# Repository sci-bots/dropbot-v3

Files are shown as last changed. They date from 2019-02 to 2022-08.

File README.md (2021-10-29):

# DropBot v3

[This wiki](https://github.com/sci-bots/dropbot-v3/wiki/) contains documentation for the DropBot Digital Microfluidics (DMF) automation system. This is the latest generation DropBot instrument (v3) which makes many improvements over the previous hardware. These systems are available for purchase from [Sci-Bots](https://sci-bots.com/dropbot).

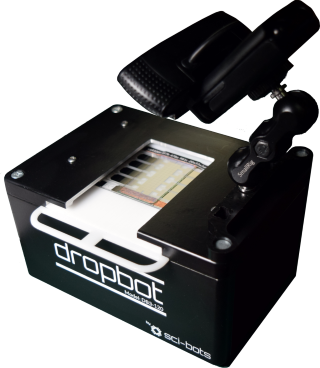
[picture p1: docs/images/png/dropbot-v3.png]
DropBot v3 (https://sci-bots.com/dropbot)


The original DropBot system was developed in the [Wheeler Lab at the University of Toronto](http://microfluidics.utoronto.ca/dropbot) and is described in detail in [Fobel et al., Appl. Phys. Lett. 102, 193513 (2013); doi: 10.1063/1.4807118](http://dx.doi.org/10.1063/1.4807118).

All hardware and software are open-source, subject to the [BSD-3-Clause license](https://github.com/sci-bots/microdrop/blob/master/LICENSE.md) (software code) or [Creative Commons Attribution-ShareAlike license](http://creativecommons.org/licenses/by-sa/3.0) (hardware designs).

If you have questions or feedback or would like to collaborate on the development of this project, please join our [community forum](https://forum.sci-bots.com). New users should checkout the [User Guide](https://github.com/sci-bots/dropbot-v3/wiki/UserGuide). If you're having problems with your DropBot, checkout the [Troubleshooting Guide](https://github.com/sci-bots/dropbot-v3/wiki/Troubleshooting).

Sci-Bots logo (https://sci-bots.com/dropbot)

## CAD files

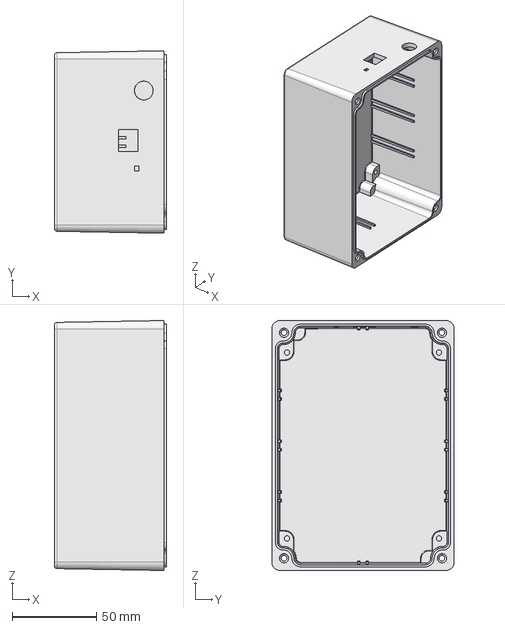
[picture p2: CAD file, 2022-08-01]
docs/step files/enclosure/Case.step
66.5 x 108.0 x 148.0 mm

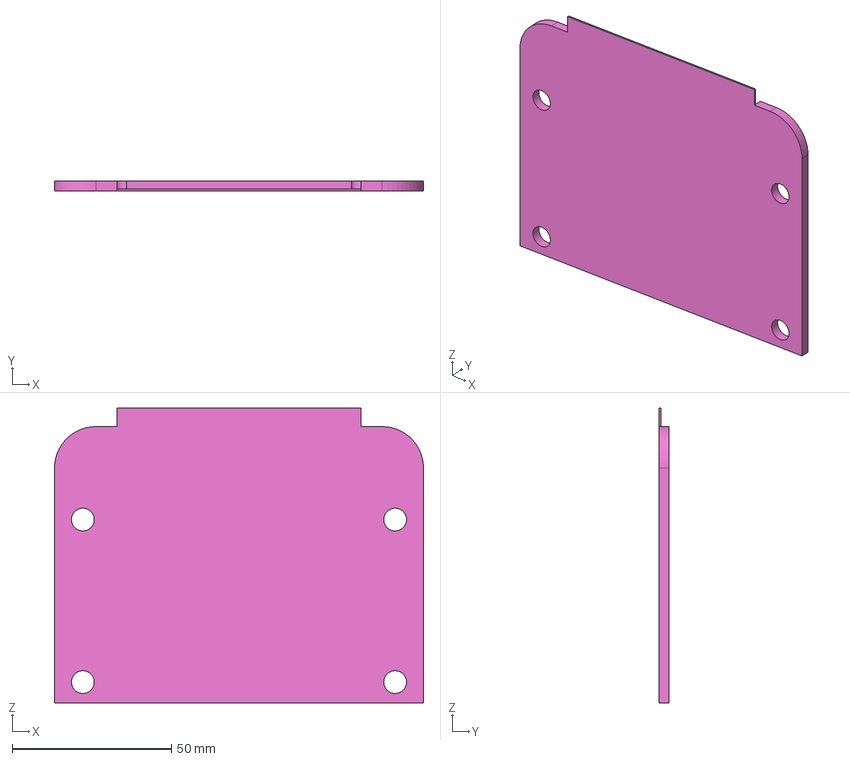
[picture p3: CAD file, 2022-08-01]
docs/step files/inner parts/Chip Guide - W115.809 x D92.555 x H3.175 mm v8 v7.step
115.8 x 3.18 x 92.6 mm

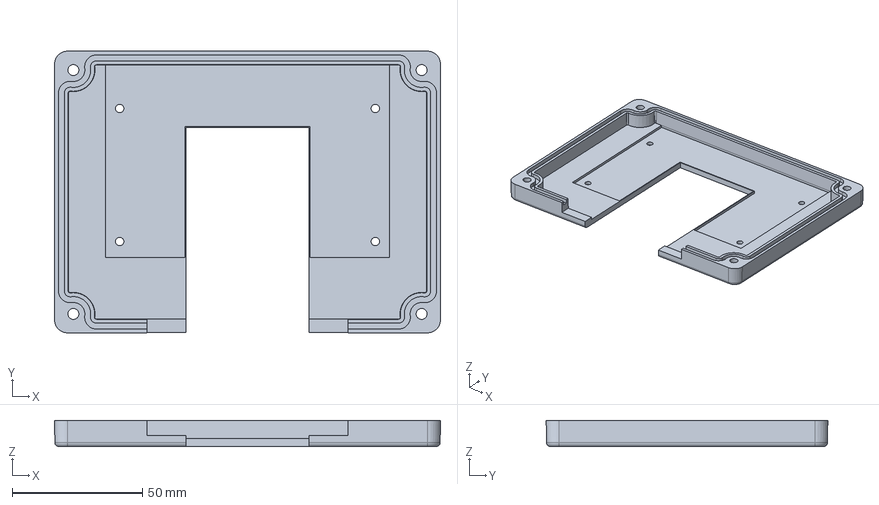
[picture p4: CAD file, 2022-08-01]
docs/step files/enclosure/Cover.step
148.0 x 108.0 x 10.0 mm

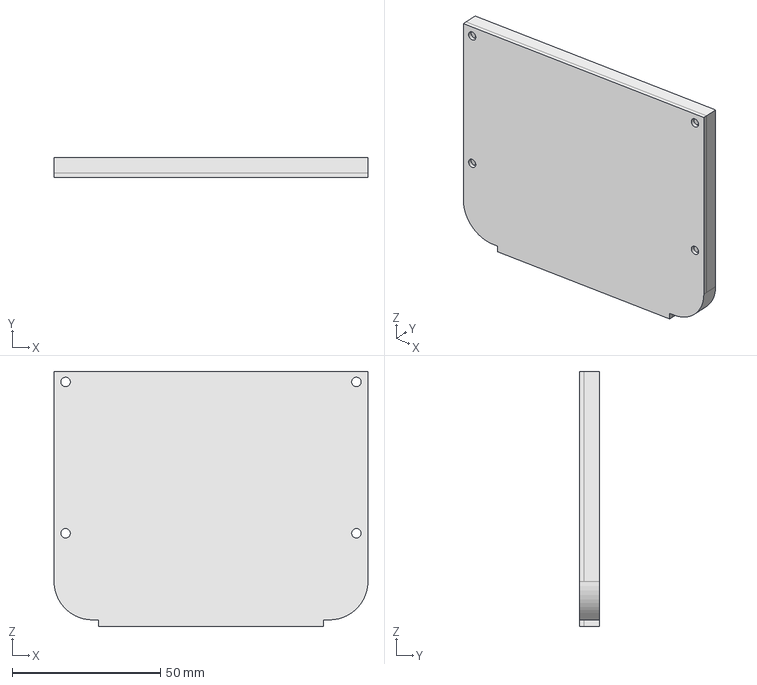
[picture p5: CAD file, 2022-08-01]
docs/step files/inner parts/base plate v6 v7.step
105.8 x 6.67 x 86.0 mm

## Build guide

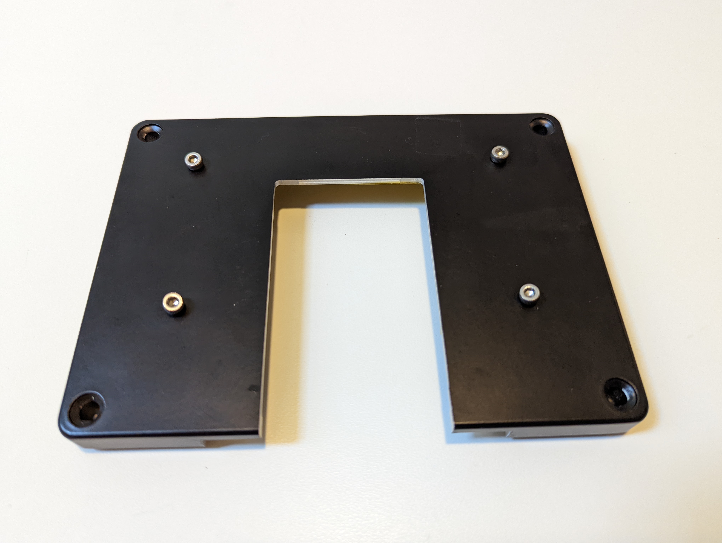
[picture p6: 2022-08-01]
docs/images/jpg/Assembly pictures/PXL_20220801_192048481.jpg

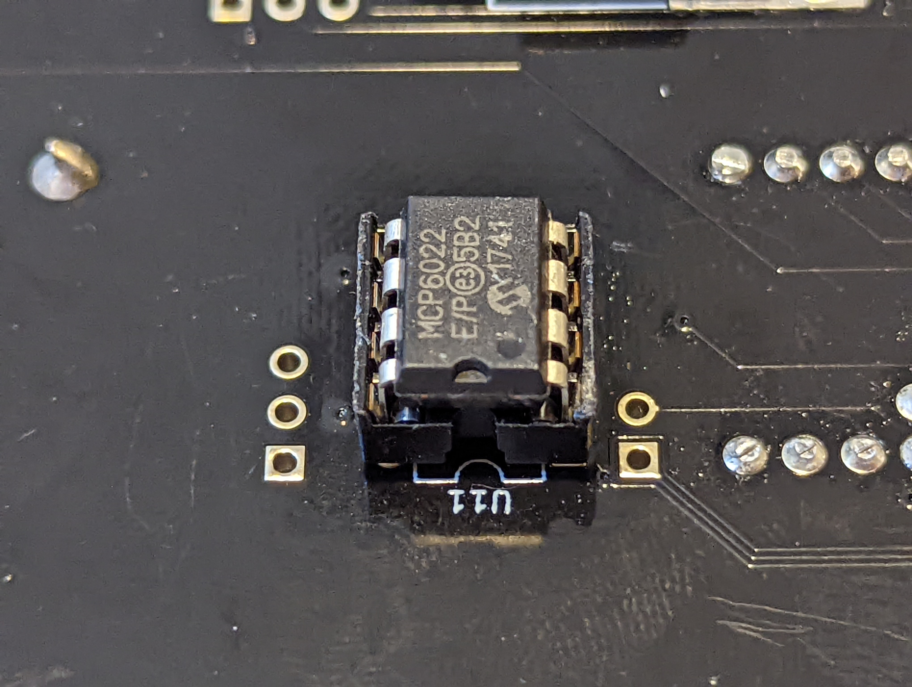
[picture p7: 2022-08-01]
docs/images/jpg/Assembly pictures/PXL_20220801_194158249.jpg

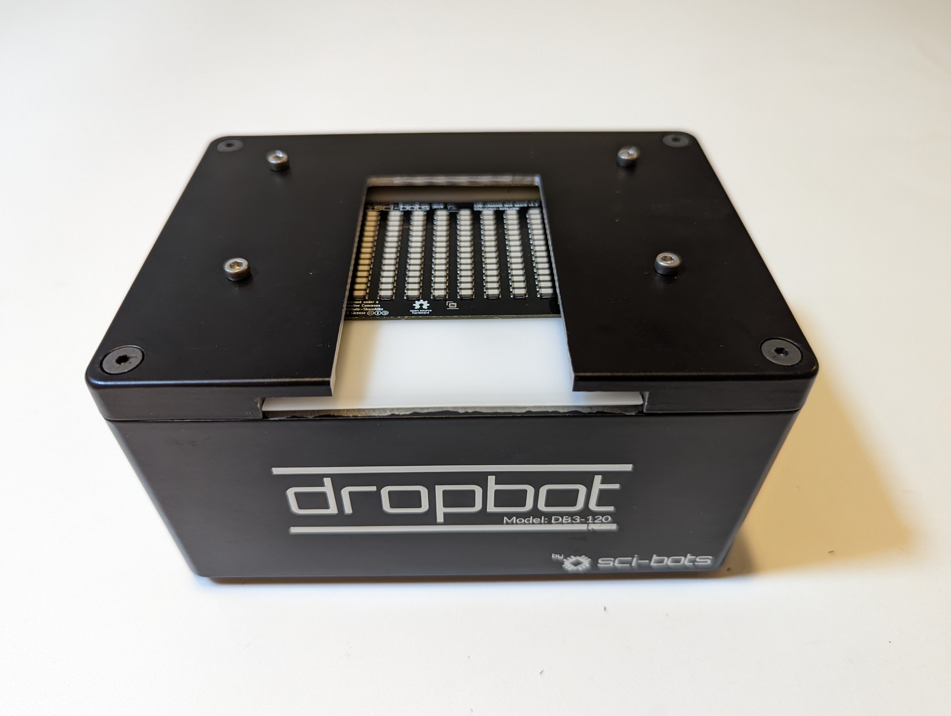
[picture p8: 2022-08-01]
docs/images/jpg/Assembly pictures/PXL_20220801_200928962.jpg

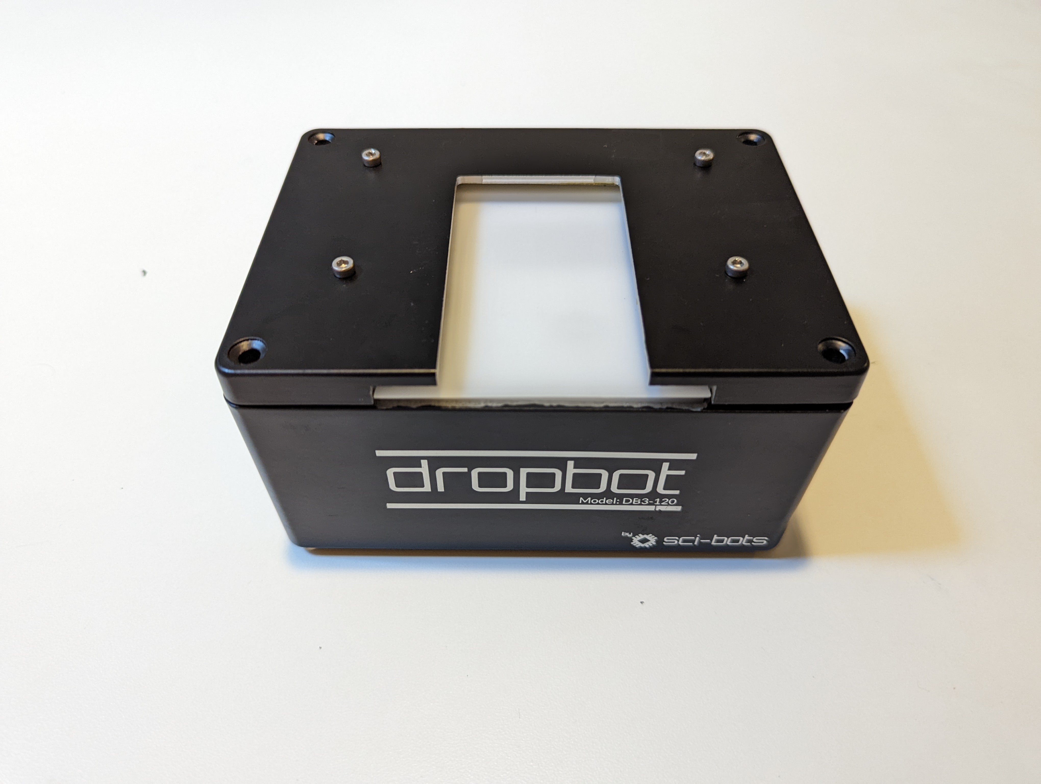
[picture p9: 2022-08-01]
docs/images/jpg/Assembly pictures/PXL_20220801_200736182.jpg

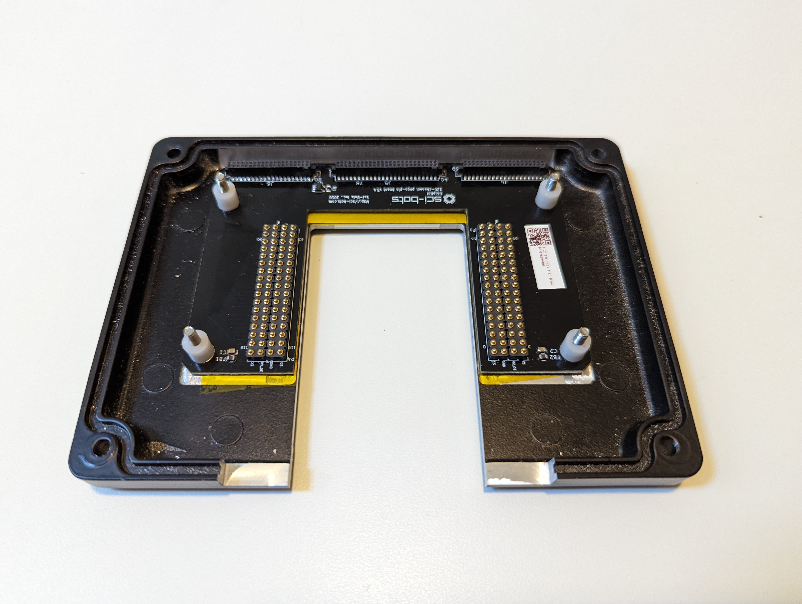
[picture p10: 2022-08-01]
docs/images/jpg/Assembly pictures/PXL_20220801_192134964.jpg

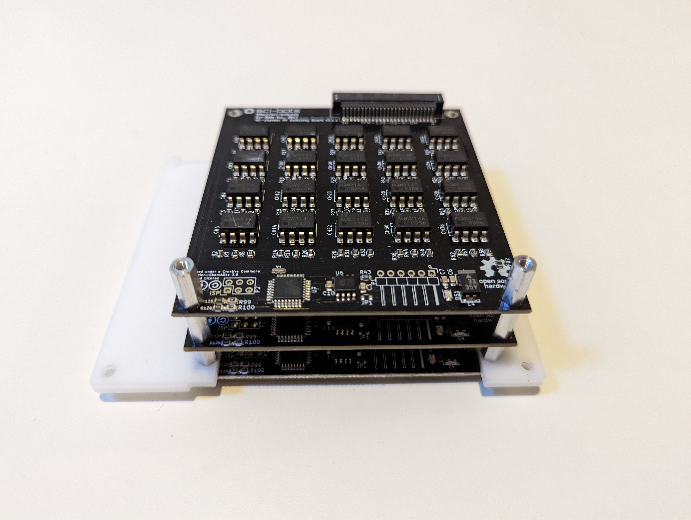
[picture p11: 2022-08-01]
docs/images/jpg/Assembly pictures/PXL_20220801_202700260.jpg

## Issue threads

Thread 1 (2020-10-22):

DropBot has halted because chip load feedback exceeded the allowable range

ryanfobel, 2020-10-22:
Sometimes an error pops up actuating too many electrodes simultaneously (especially larger reservoirs):

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

# Background

The DropBot is constantly measuring the current passing from the ```high-voltage source``` -> ```actuation electrodes``` -> ```top-plate``` -> ```feedback pin```. If this current exceeds a certain threshold, the DropBot is programmed to halt operation and disable the high-voltage source (until the hardware is reset) to prevent damage to it's internal circuitry. This could happen if a chip is damaged (e.g., through dielectric breakdown) or due to an unintended short circuit. Unfortunately, the threshold limit is probably a bit too low, which means that it can sometimes be triggered during normal operation of the system.

The chip load signal is a mirror of the current passing through the chip; scaled down within the range of the Teensy's ADC input:

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

This signal is used to compute the impedance across all actuated electrodes.

Some points to note:

* The chip load is an AC signal, biased about 0.6 V.
* If the amplitude of the chip load signal is too high, the ADC input will saturate; i.e., will either increase above the maximum ADC input or below 0.
* Chip load amplitude (i.e., current through the chip) is inversely proportional to the chip impedance (for a given actuation voltage). The increase in chip load amplitude increases with each additional actuated electrode that is covered with liquid; as the impedance of liquid is much, much less than the impedance of air.
* The DropBot detects saturation of the chip load signal according to the ```proxy.state.chip_load_range_margin``` (default: 0.03, i.e., 3% of the ADC range - see m in the image above) setting.
* Currently, the chip load pin is measured every 25 ms and an error is reported if a measurement is within ```proxy.state.chip_load_range_margin``` of the upper or lower limit of the ADC range (see “saturated” label in image above).

# Disabling the chip load saturation check via software

Prior to ```dropbot=1.70.0```, there was no way to disable the chip load saturation check. However, as of ```dropbot>=1.70.0```, we have added the ability to explicitly disable the chip load saturation check by setting ```proxy.state.chip_load_range_margin``` to a negative value). The issue with completely disabling the limit is that if/when you get electrolsis, you could damage the DropBot if it can't shut itself off.

# Increasing the chip load saturation threshold via hardware/software modification

## Hardware change

A better solution would be to increase the chip load saturation threshold without disabling the check. This can be done by replacing ```C16``` (0.15uF) on the control board with a larger capacitor (e.g., 0.33uF) which would increase the saturation limit and still allow the DropBot to detect shorts.

```
C_max = (ADC_Vmax / V_actuation)*C16
```

Assuming ```V_actuation```=120V at ```f```=10kHz and ```ADC_Vmax```=1.2V, the largest capacitance you can measure is 100*```C16```. So for ```C16```=0.15uF, ```C_max```=1.5nF. Increasing ```C16``` to 0.33uF increases the limit to ```C_max```=3.3nF. Note that we need to ensure that ```C16```<0.4uF or we risk damaging the op amp (U11), which supports a max current of 30mA.

```
i=ADC_Vmax/(2*pi*C16*f)
```

## Software change

As of version ```dropbot>=1.72.0```, the value for capacitor C16 is hard-coded as 150nF (see ```channels.h``` lines 343-350).

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

```dropbot=1.73.1``` implemented the new abilities to store the capacitance value of ```C16``` in EEPROM, and to calibrate the ```C16``` capacitor against a known test load capacitance (e.g., the test board, on-board capacitors), but the old value 0.15uF was still hard-coded in the [```measure_capacitance method```](https://gitlab.com/sci-bots/dropbot.py/-/blob/v1.73.3/dropbot/proxy_py2.py#L422). This was fixed in [```dropbot=1.73.4```](https://gitlab.com/sci-bots/dropbot.py/-/commit/5dc1938b4459f6144eff221ee0abc9b531172871).

ryanfobel, 2021-05-21:
All DropBots sold after 2021-05-01 include a larger feedback capacitor (C16=0.33uF). These systems MUST be run with [MicroDrop v3.1.2](https://github.com/sci-bots/microdrop/releases/tag/v3.1.2) or higher. If you have an older DropBot and would like to perform this modification, please contact support@sci-bots.com.

Closed 2021-05-21.

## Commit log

2021-10-25 Add test board
2021-11-05 Update switching board and test board submodules
2021-11-12 Add kicad_helpers notebook and update submodules
2021-11-25 Add badges to kicad_helpers notebook
2022-08-01 Added enclosure design files
    [Case.step, Cover.step]
2022-08-01 Added results-summary images
    Used in [DropBot assembly instructions](https://github.com/sci-bots/dropbot-v3/wiki/DropBot-assembly-instructions).
2022-08-01 DropBot assembly process pictures
    Used in the [DropBot assembly instructions](https://github.com/sci-bots/dropbot-v3/wiki/DropBot-assembly-instructions) page on the wiki.
2022-08-01 Creating .step files repo
    [Chip Guide - W115.809 x D92.555 x H3.175 mm v8 v7.step, base plate v6 v7.step]
